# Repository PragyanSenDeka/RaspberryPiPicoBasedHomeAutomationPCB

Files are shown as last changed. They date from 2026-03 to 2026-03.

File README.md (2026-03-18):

PicoW Smart Home Automation Controller

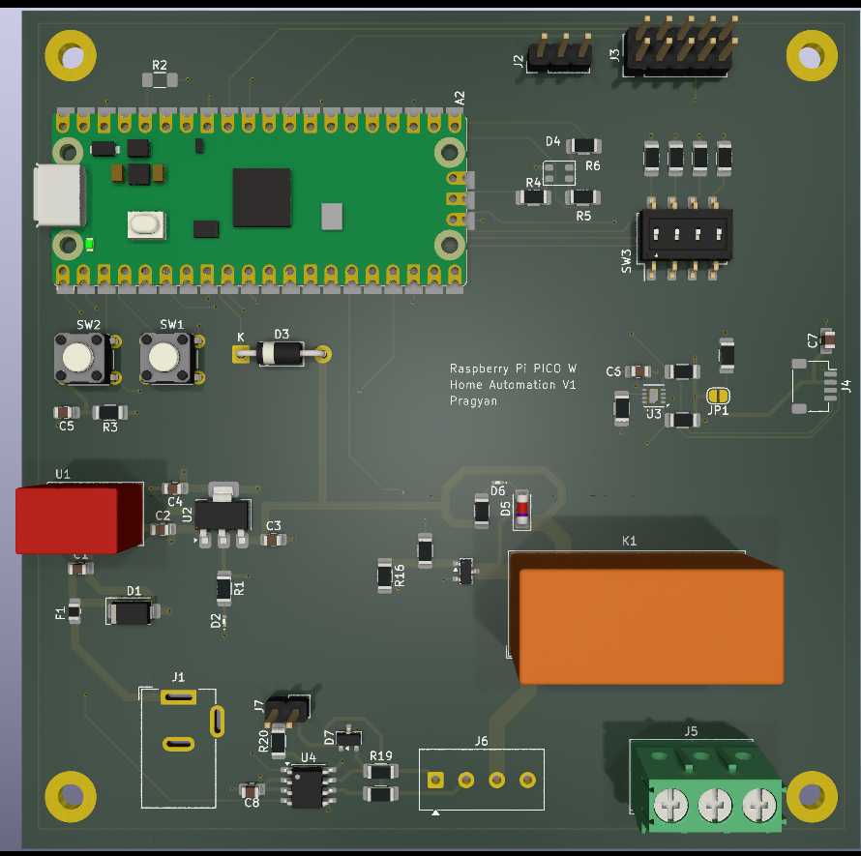
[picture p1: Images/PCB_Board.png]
System Diagram


A robust home automation controller built around the Raspberry Pi Pico W, designed for reliable operation in real-world environments. It combines industrial communication (MODBUS over RS485) with modern IoT capabilities, making it suitable for smart homes, labs, and distributed control systems.

Features

Raspberry Pi Pico W (or compatible variants) for wireless connectivity

RS485 / MODBUS interface for industrial-grade communication

DIP switch-based MODBUS address selection for easy multi-node deployment

SHT31-DIS high-precision temperature and humidity sensor

QWIIC connector for plug-and-play I2C expansion

Reset button and user button for control and interaction

User RGB LED for status indication and debugging

2x5 SPI expansion header for additional peripherals

High-power relay (230V, 16A) for controlling appliances

Wide input voltage support: 8V to 24V DC

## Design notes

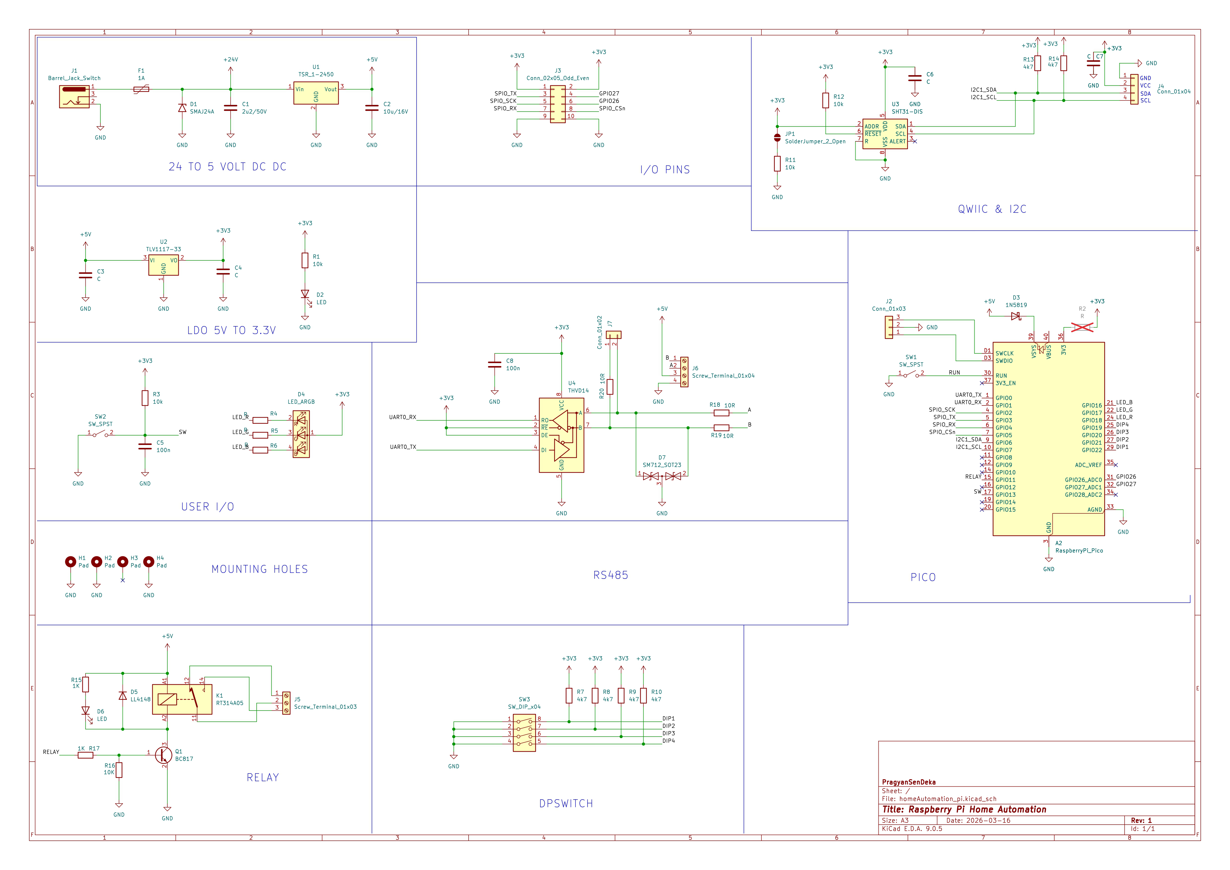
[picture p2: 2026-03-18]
Images/Schematic.jpg

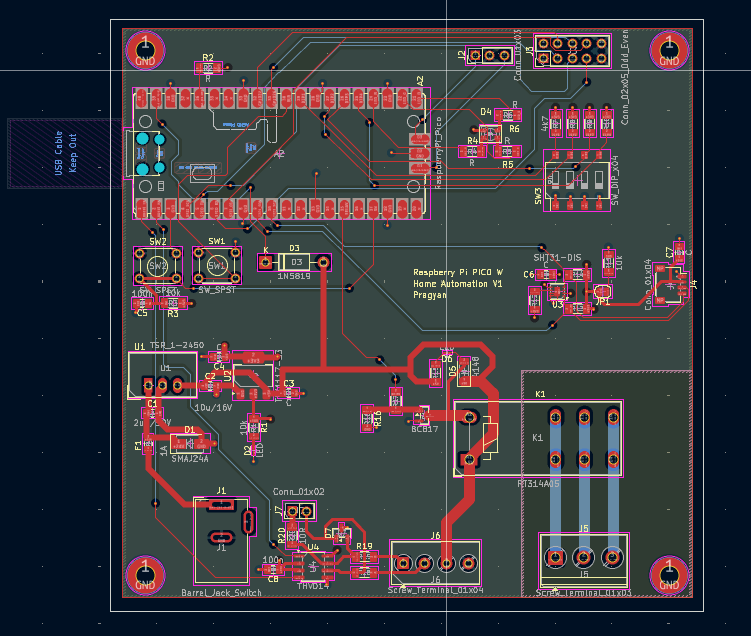
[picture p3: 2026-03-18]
Images/Layout.png

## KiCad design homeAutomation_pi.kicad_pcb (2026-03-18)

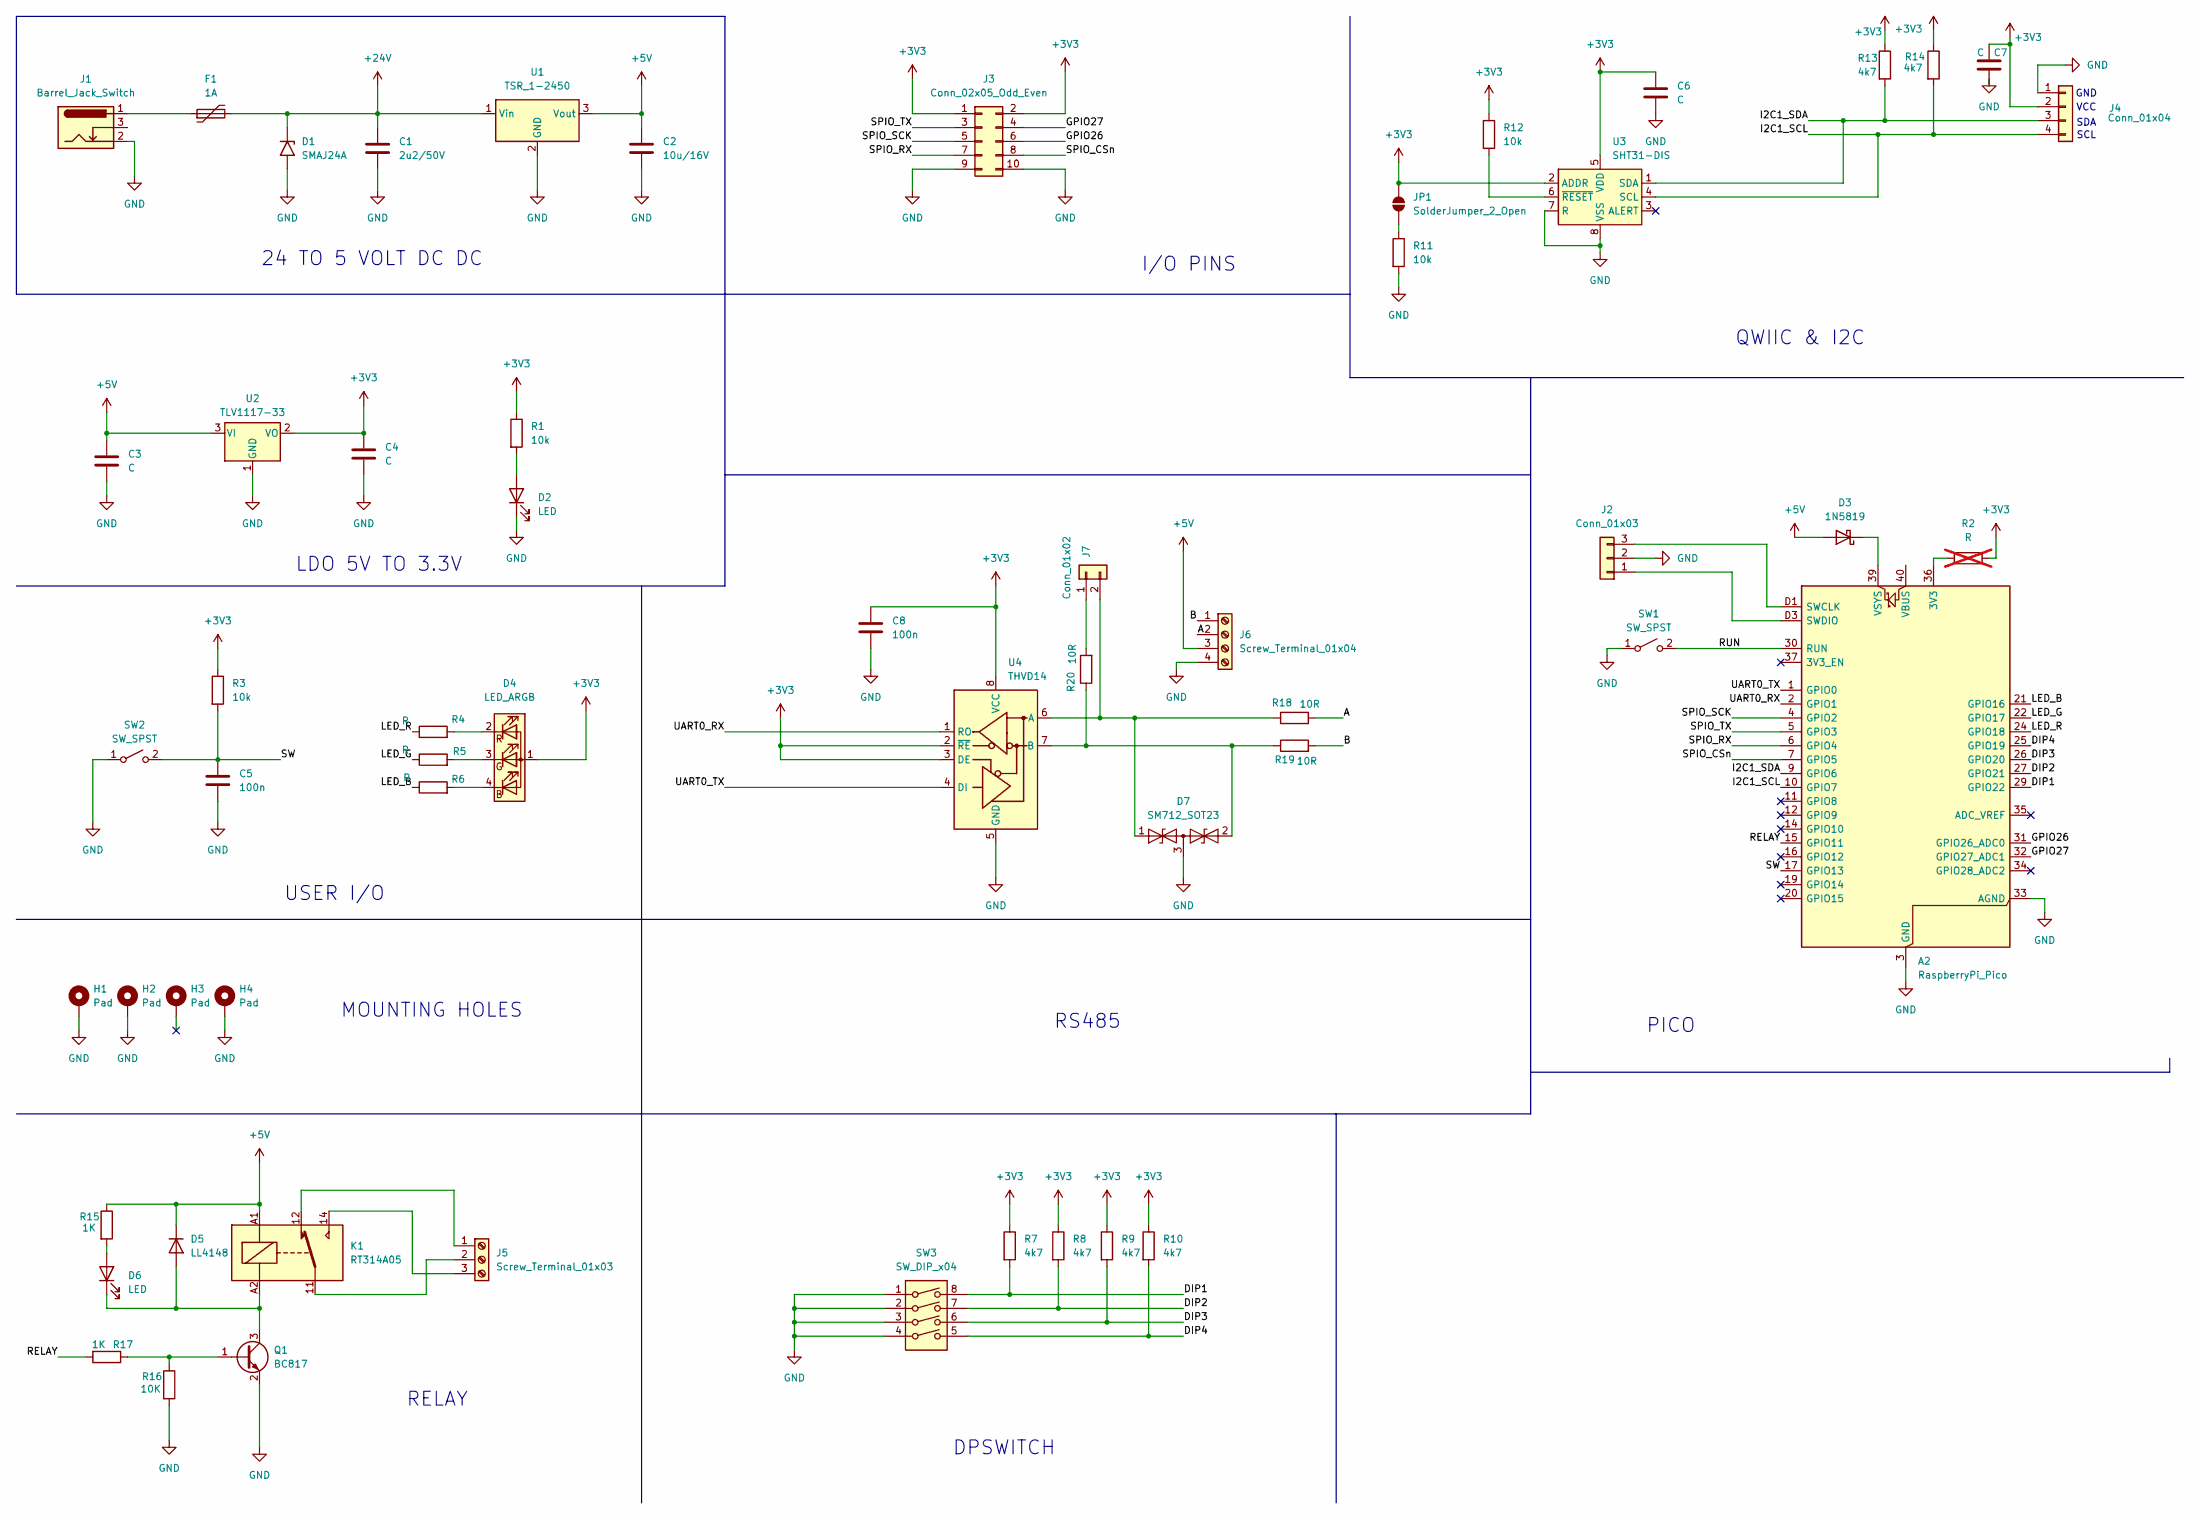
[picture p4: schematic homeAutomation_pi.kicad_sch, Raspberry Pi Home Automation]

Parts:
A2: RaspberryPi_Pico; RaspberryPi_Pico_SMD_HandSolder
C1: 2u2/50V; C_0805_2012Metric_Pad1.18x1.45mm_HandSolder
C2: 10u/16V; C_0805_2012Metric_Pad1.18x1.45mm_HandSolder
C3, C4, C6, C7: C; C_0805_2012Metric_Pad1.18x1.45mm_HandSolder
C5, C8: 100n; C_0805_2012Metric_Pad1.18x1.45mm_HandSolder
D1: SMAJ24A; D_SMA
D2: LED; LED_0201_0603Metric_Pad0.64x0.40mm_HandSolder
D3: 1N5819; D_DO-41_SOD81_P10.16mm_Horizontal
D4: LED_ARGB; LED_Cree-PLCC4_3.2x2.8mm_CCW
D5: LL4148; D_MiniMELF
D6: LED; LED_0805_2012Metric_Pad1.15x1.40mm_HandSolder
D7: SM712_SOT23; SOT-23
F1: 1A; Fuse_0805_2012Metric_Pad1.15x1.40mm_HandSolder
H1, H2, H3, H4: Pad; MountingHole_3.2mm_M3_Pad
J1: Barrel_Jack_Switch; BarrelJack_Wuerth_6941xx301002
J2: Conn_01x03; PinHeader_1x03_P2.54mm_Vertical
J3: Conn_02x05_Odd_Even; PinHeader_2x05_P2.54mm_Vertical
J4: Conn_01x04; PinHeader_1x04_P2.54mm_Vertical
J5: Screw_Terminal_01x03; TerminalBlock_Phoenix_PT-1,5-3-5.0-H_1x03_P5.00mm_Horizontal
J6: Screw_Terminal_01x04; TerminalBlock_Phoenix_MKDS-1-4-3.81_1x04_P3.81mm_Horizontal
J7: Conn_01x02; PinHeader_1x02_P2.54mm_Vertical
JP1: SolderJumper_2_Open; SolderJumper-2_P1.3mm_Open_RoundedPad1.0x1.5mm
K1: RT314A05; Relay_SPDT_Schrack-RT1-16A-FormC_RM5mm
Q1: BC817; SOT-23
R1, R3, R11, R12: 10k; R_1206_3216Metric_Pad1.30x1.75mm_HandSolder
R2: R; R_1206_3216Metric_Pad1.30x1.75mm_HandSolder; not fitted
R4, R5, R6: R; R_1206_3216Metric_Pad1.30x1.75mm_HandSolder
R7, R8, R9, R10, R13, R14: 4k7; R_1206_3216Metric_Pad1.30x1.75mm_HandSolder
R15, R17: 1K; R_1206_3216Metric_Pad1.30x1.75mm_HandSolder
R16: 10K; R_1206_3216Metric_Pad1.30x1.75mm_HandSolder
R18, R19, R20: 10R; R_1206_3216Metric_Pad1.30x1.75mm_HandSolder
SW1, SW2: SW_SPST; SW_TH_Tactile_Omron_B3F-100x
SW3: SW_DIP_x04; SW_DIP_SPSTx04_Slide_Omron_A6S-410x_W8.9mm_P2.54mm
U1: TSR_1-2450; Converter_DCDC_TRACO_TSR-1_THT
U2: TLV1117-33; SOT-223-3_TabPin2
U3: SHT31-DIS; Sensirion_DFN-8-1EP_2.5x2.5mm_P0.5mm_EP1.1x1.7mm
U4: THVD14; SOIC-8_3.9x4.9mm_P1.27mm

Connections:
+3V3: C4.1, C6.1, C7.1, C8.1, D4.1 (A), J3.1, J3.2, J4.2, JP1.2 (B), R1.1, R2.2, R3.1, R7.1, R8.1, R9.1, R10.1, R12.1, R13.1, R14.1, U2.2 (VO), U3.2 (ADDR), U3.5 (VDD), U4.2 (~RE), U4.3 (DE), U4.8 (VCC)
+5V: C2.1, C3.1, D3.2 (A), D5.1 (K), J6.3, K1.A1, R15.1, U1.3 (Vout), U2.3 (VI)
+24V: C1.1, D1.1 (A1), F1.2, U1.1 (Vin)
/A: J6.2, R18.2
/B: J6.1, R19.2
/DIP1: A2.29 (GPIO22), R7.2, SW3.8
/DIP2: A2.27 (GPIO21), R8.2, SW3.7
/DIP3: A2.26 (GPIO20), R9.2, SW3.6
/DIP4: A2.25 (GPIO19), R10.2, SW3.5
/GPIO26: A2.31 (GPIO26_ADC0), J3.6
/GPIO27: A2.32 (GPIO27_ADC1), J3.4
/I2C1_SCL: A2.10 (GPIO7), J4.4, R14.2, U3.4 (SCL)
/I2C1_SDA: A2.9 (GPIO6), J4.3, R13.2, U3.1 (SDA)
/LED_B: A2.21 (GPIO16), R6.1
/LED_G: A2.22 (GPIO17), R5.1
/LED_R: A2.24 (GPIO18), R4.1
/RELAY: A2.15 (GPIO11), R17.2
/RUN: A2.30 (RUN), SW1.2 (B)
/SPIO_CSn: A2.7 (GPIO5), J3.8
/SPIO_RX: A2.6 (GPIO4), J3.7
/SPIO_SCK: A2.4 (GPIO2), J3.5
/SPIO_TX: A2.5 (GPIO3), J3.3
/SW: A2.17 (GPIO13), C5.1, R3.2, SW2.2 (B)
/UART0_RX: A2.2 (GPIO1), U4.1 (RO)
/UART0_TX: A2.1 (GPIO0), U4.4 (DI)
GND: A2.3 (GND), A2.8 (GND), A2.13 (GND), A2.18 (GND), A2.23 (GND), A2.28 (GND), A2.33 (AGND), A2.38 (GND), A2.D2 (GND), C1.2, C2.2, C3.2, C4.2, C5.2, C6.2, C7.2, C8.2, D1.2 (A2), D2.1 (K), D7.3 (common), H1.1, H2.1, H3.1, H4.1, J1.2, J2.2, J3.9, J3.10, J4.1, J6.4, Q1.2 (E), R11.2, R16.2, SW1.1 (A), SW2.1 (A), SW3.1, SW3.2, SW3.3, SW3.4, U1.2 (GND), U2.1 (GND), U3.7 (R), U3.8 (VSS), U3.9 (VSS), U4.5 (GND)
unnamed: A2.36 (3V3), R2.1
unnamed: A2.D1 (SWCLK), J2.3
unnamed: A2.D3 (SWDIO), J2.1
unnamed: A2.39 (VSYS), D3.1 (K)
unnamed: D2.2 (A), R1.2
unnamed: D4.4 (BK), R6.2
unnamed: D4.3 (GK), R5.2
unnamed: D4.2 (RK), R4.2
unnamed: D5.2 (A), D6.1 (K), K1.A2, Q1.3 (C)
unnamed: D6.2 (A), R15.2
unnamed: D7.1 (A1), J7.2, R18.1, U4.6 (A)
unnamed: D7.2 (A2), R19.1, R20.1, U4.7 (B)
unnamed: F1.1, J1.1
unnamed: J5.1, K1.12
unnamed: J5.2, K1.11
unnamed: J5.3, K1.14
unnamed: J7.1, R20.2
unnamed: JP1.1 (A), R11.1
unnamed: Q1.1 (B), R16.1, R17.1
unnamed: R12.2, U3.6 (~RESET)

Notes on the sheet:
VCC
MOUNTING HOLES
SCL
SDA
USER I/O
PICO
RS485
LDO 5V TO 3.3V
GND
QWIIC & I2C
RELAY
DPSWITCH
I/O PINS
24 TO 5 VOLT DC DC

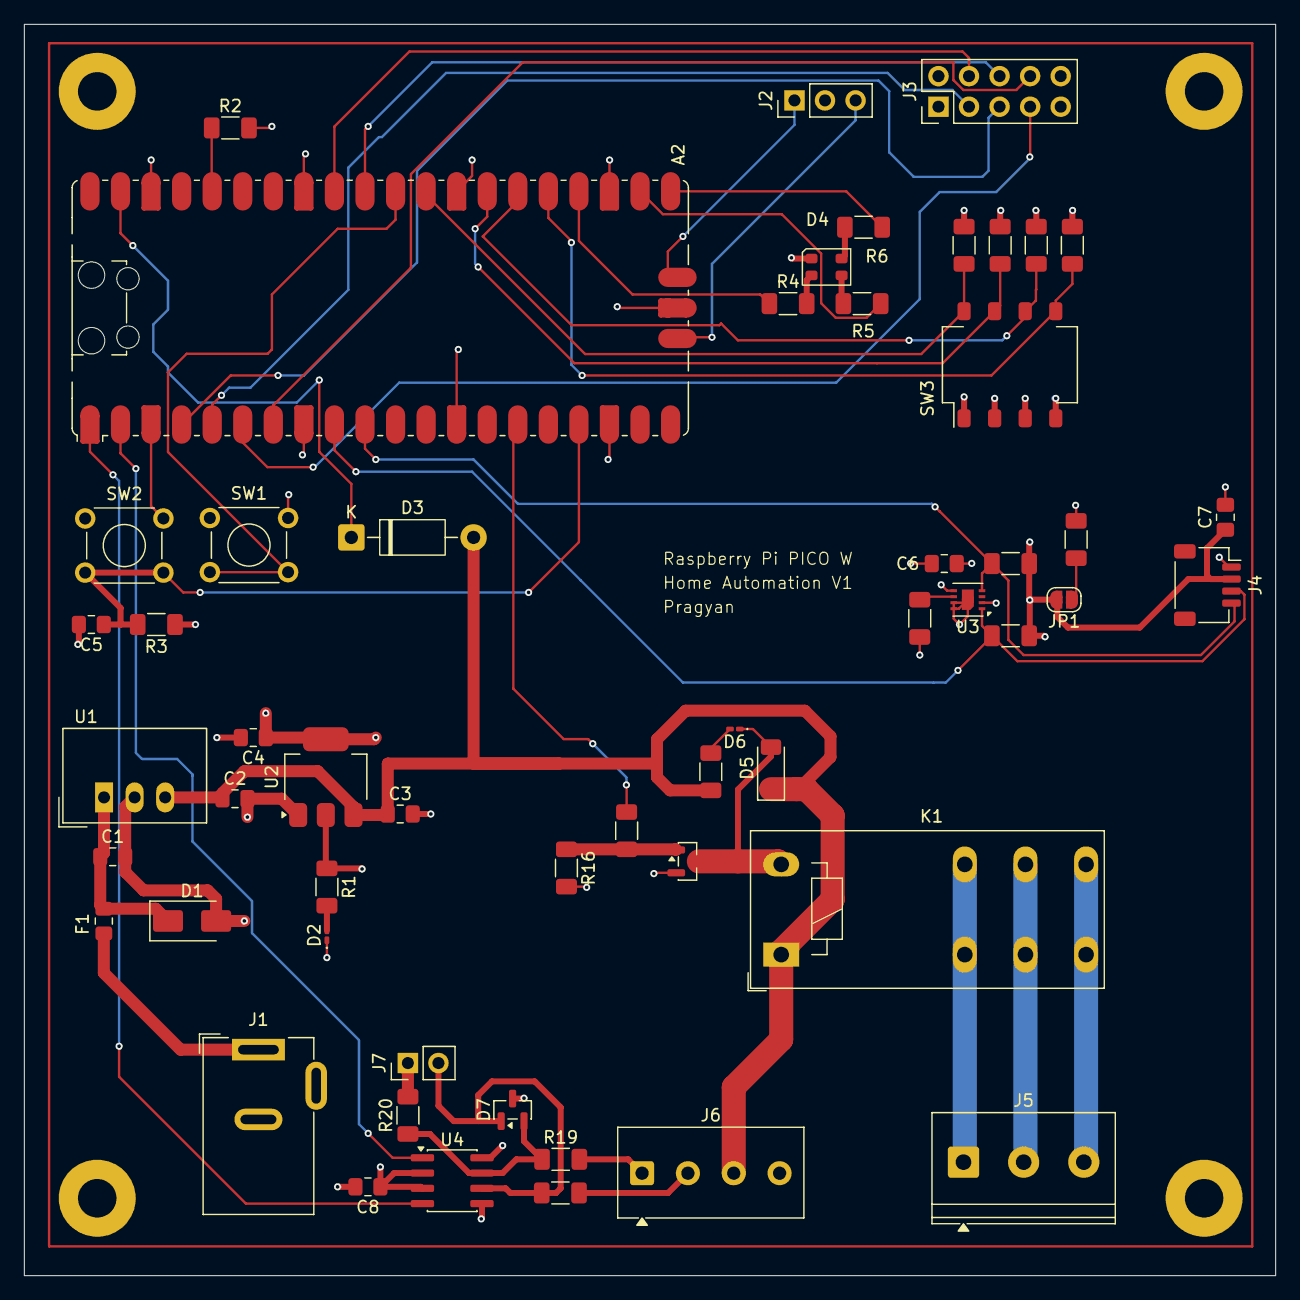
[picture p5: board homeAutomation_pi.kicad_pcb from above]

Board: 4 copper layers, 104.0 x 104.0 mm, 58 parts (0 on the bottom side), 46 nets.
